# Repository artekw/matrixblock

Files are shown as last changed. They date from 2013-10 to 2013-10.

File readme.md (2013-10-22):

# matrixblock

The goal of this project is create a cape for BeagleBone Black to drive a [Sure Electronic 32x16 LED Display](http://www.sureelectronics.net/goods.php?id=1095).

## Hardware Connection

matrix connection to beaglebone

Power circuit from matrix connector, not BeagleBone! Use power adapter 5V/2A.

## Compile the code

TODO

Examples:

    $ cd examples
    $ make
    $ ./test

Clock:

    $ make
    $ ./clock

### TODO

- python bindings or TCP deamon

### DONE

- print static text
- scroll text
- set brightness (in range 0-16)
- schematics and PCB design of cape
- DT code and EEEPROM firmware
- add RTC clock

### Source

Based on source code from https://github.com/dcuartielles/HT1632c

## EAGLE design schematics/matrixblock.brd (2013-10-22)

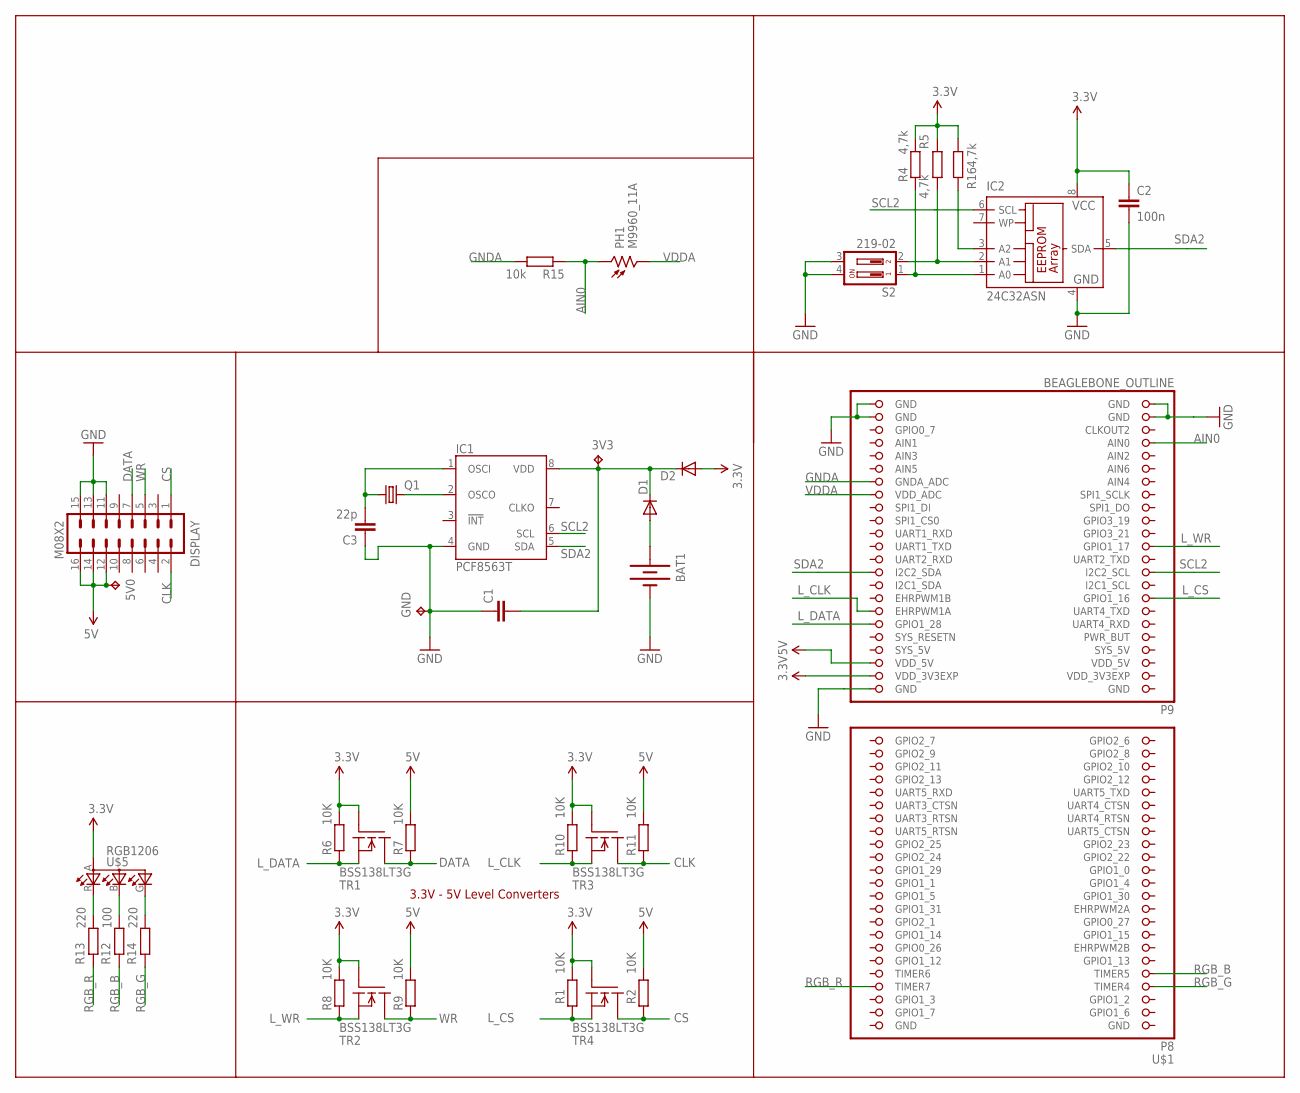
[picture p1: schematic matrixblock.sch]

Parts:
3V3, 5V0: TPTP20R; TP20R
BAT1: BATTERY20PTH; BATTCOM_20MM_PTH
C1: C-EUC0805; C0805
C2: 100n; C0805
C3: 22p; C0805
D1, D2: DIODEHV; DIODE-HV
DISPLAY: M08X2; 2X8
GND: TPTP20R; TP20R
IC1: PCF8563T; SO8
IC2: 24C32ASN; SO-08
PH1: M9960_11A; M9960
Q1: CRYSTALTC26H; TC26H
R1, R2, R6, R7, R8, R9, R10, R11: 10K; R0805
R4, R5, R16: 4,7k; R0805
R12: 100; R0805
R13, R14: 220; R0805
R15: 10k; R0805
S2: 219-02; CTS-219-02
TR1, TR2, TR3, TR4: BSS138LT3G; SOT23
U$1: BEAGLEBONE_OUTLINE; BEAGLEBONE_SHIELD
U$5: RGB1206

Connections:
3.3V: D2.A, R1.1, R6.1, R8.1, R10.1, TR1.1 (G), TR2.1 (G), TR3.1 (G), TR4.1 (G), U$1.50 (VDD_3V3EXP), U$5.A
5V: 5V0.TP, DISPLAY.12, DISPLAY.14, DISPLAY.16, R2.1, R7.1, R9.1, R11.1, U$1.52 (VDD_5V)
AIN0: PH1.1, R15.2, U$1.85 (AIN0)
CLK: DISPLAY.2, R11.2, TR3.3 (D)
CS: DISPLAY.1, R2.2, TR4.3 (D)
DATA: DISPLAY.7, R7.2, TR1.3 (D)
GND: BAT1.2 (-), C1.1, C2.2, C3.1, DISPLAY.11, DISPLAY.13, DISPLAY.15, GND.TP, IC1.4 (GND), IC2.4 (GND), S2.3, S2.4, U$1.1 (GND), U$1.2 (GND), U$1.47 (GND), U$1.48 (GND), U$1.89 (GND), U$1.90 (GND), U$1.91 (GND), U$1.92 (GND)
GNDA: R15.1, U$1.80 (GNDA_ADC)
L_CLK: R10.2, TR3.2 (S), U$1.60 (EHRPWM1A)
L_CS: R1.2, TR4.2 (S), U$1.61 (GPIO1_16)
L_DATA: R6.2, TR1.2 (S), U$1.58 (GPIO1_28)
L_WR: R8.2, TR2.2 (S), U$1.69 (GPIO1_17)
unnamed: BAT1.1 (+), D1.A
unnamed: R12.1, U$5.B (CBLUE)
unnamed: IC1.2 (OSCO), Q1.2
unnamed: C3.2, IC1.1 (OSCI), Q1.1
unnamed: R13.1, U$5.R (CRED)
unnamed: 3V3.TP, C1.2, D1.C, D2.C, IC1.8 (VDD)
unnamed: R14.1, U$5.G (CGREEN)
unnamed: IC2.3 (A2), R16.2
unnamed: IC2.2 (A1), R5.1, S2.2
unnamed: IC2.1 (A0), R4.2, S2.1
RGB_B: R12.2, U$1.9 (TIMER5)
RGB_G: R14.2, U$1.7 (TIMER4)
RGB_R: R13.2, U$1.8 (TIMER7)
SCL2: IC1.6 (SCL), IC2.6 (SCL), U$1.65 (I2C2_SCL)
SDA2: IC1.5 (SDA), IC2.5 (SDA), U$1.66 (I2C2_SDA)
SYS_5V: U$1.53 (SYS_5V)
VCC: C2.1, IC2.8 (VCC), R4.1, R5.2, R16.1
VDDA: PH1.2, U$1.78 (VDD_ADC)
VDD_3V3EXP: U$1.49 (VDD_3V3EXP)
VDD_5V: U$1.51 (VDD_5V)
WR: DISPLAY.5, R9.2, TR2.3 (D)

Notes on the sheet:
3.3V - 5V Level Converters

Board: 2 copper layers, 36 parts (1 on the bottom side), 30 nets, no tracks yet.

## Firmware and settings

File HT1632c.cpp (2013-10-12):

#include "HT1632c.h"
#include "fonts.c"
#include <stdlib.h>
#include <stdio.h>
#include <time.h>
#include "BoneHeader/BoneHeader.h"

// our own copy of the "video" memory; 64 bytes for each of the 4 screen quarters;
// each 64-element array maps 2 planes:
// indexes from 0 to 31 are allocated for green plane;
// indexes from 32 to 63 are allocated for red plane;
// when a bit is 1 in both planes, it is displayed as orange (green + red);
unsigned char ht1632_shadowram[64][4*2] = {0};

// constructor:
// assign pins, one single screen
HT1632c::HT1632c(char bank, char da, char wr, char cs, char cl)
{
      ht1632_data = da;  // Data pin (pin 7 of display connector)
      ht1632_wrclk = wr; // Write clock pin (pin 5 of display connector)
      ht1632_cs = cs;    // Chip Select (pin 1 of display connnector)
      ht1632_clk = cl;   // clock pin (pin 2 of display connector)
      Number_of_Displays = 1;
      CHIP_MAX =  4*Number_of_Displays; // Four HT1632Cs on one board
      X_MAX = 32*Number_of_Displays;
      Y_MAX = 16;

      if (is_exported_gpio(bank * 32 + ht1632_data) == false) {
        export_gpio(bank * 32 + ht1632_data);
        set_gpio_direction(bank * 32 + ht1632_data, "out");
      }
      if (is_exported_gpio(bank * 32 + ht1632_wrclk) == false) {
        export_gpio(bank * 32 + ht1632_wrclk);
        set_gpio_direction(bank * 32 + ht1632_wrclk, "out");
      }
      if (is_exported_gpio(bank * 32 + ht1632_cs) == false) {
        export_gpio(bank * 32 + ht1632_cs);
        set_gpio_direction(bank * 32 + ht1632_cs, "out");
      }
      if (is_exported_gpio(bank * 32 + ht1632_clk) == false) {
        export_gpio(bank * 32 + ht1632_clk);
        set_gpio_direction(bank * 32 + ht1632_clk, "out");
      }

      gpiobank = new GPIO_MMAP(bank);

      if (ht1632_cs > 0) {
        gpiobank->write(ht1632_cs, 1);
      }
      if (ht1632_wrclk > 0) {
        gpiobank->write(ht1632_wrclk, 1);
      }
      if (ht1632_data > 0) {
        gpiobank->write(ht1632_data, 1);
      }
      if (ht1632_clk > 0) {
        gpiobank->write(ht1632_clk, 1);
      }

      ts.tv_sec = 0;
      ts.tv_nsec = DELAY;
}

// constructor:
// assign pins, multiple single screen
HT1632c::HT1632c(char bank, char a, char da, char wr, char cs, char cl)
{
      ht1632_data = da;  // Data pin (pin 7 of display connector)
      ht1632_wrclk = wr; // Write clock pin (pin 5 of display connector)
      ht1632_cs = cs;    // Chip Select (pin 1 of display connnector)
      ht1632_clk = cl;   // clock pin (pin 2 of display connector)
      Number_of_Displays = a;
      CHIP_MAX =  4*Number_of_Displays; // Four HT1632Cs on one board
      X_MAX = 32*Number_of_Displays;
      Y_MAX = 16;

      if (is_exported_gpio(bank * 32 + ht1632_data) == false) {
        export_gpio(bank * 32 + ht1632_data);
        set_gpio_direction(bank * 32 + ht1632_data, "out");
      }
      if (is_exported_gpio(bank * 32 + ht1632_wrclk) == false) {
        export_gpio(bank * 32 + ht1632_wrclk);
        set_gpio_direction(bank * 32 + ht1632_wrclk, "out");
      }
      if (is_exported_gpio(bank * 32 + ht1632_cs) == false) {
        export_gpio(bank * 32 + ht1632_cs);
        set_gpio_direction(bank * 32 + ht1632_cs, "out");
      }
      if (is_exported_gpio(bank * 32 + ht1632_clk) == false) {
        export_gpio(bank * 32 + ht1632_clk);
        set_gpio_direction(bank * 32 + ht1632_clk, "out");
      }

      gpiobank = new GPIO_MMAP(bank);

      if (ht1632_cs > 0) {
        gpiobank->write(ht1632_cs, 1);
      }
      if (ht1632_wrclk > 0) {
        gpiobank->write(ht1632_wrclk, 1);
      }
      if (ht1632_data > 0) {
        gpiobank->write(ht1632_data, 1);
      }
      if (ht1632_clk > 0) {
        gpiobank->write(ht1632_clk, 1);
      }

      //ts.tv_sec = 0;
      //ts.tv_nsec = DELAY;
}

//**************************************************************************************************
//Function Name: OutputCLK_Pulse
//Function Feature: enable CLK_74164 pin to output a clock pulse
//Input Argument: void
//Output Argument: void
//**************************************************************************************************
void HT1632c::OutputCLK_Pulse(void) //Output a clock pulse
{
  gpiobank->write(ht1632_clk, 1);
  gpiobank->write(ht1632_clk, 0);
}


//**************************************************************************************************
//Function Name: OutputA_74164
//Function Feature: enable pin A of 74164 to output 0 or 1
//Input Argument: x: if x=1, 74164 outputs 1. If x?1, 74164 outputs 0.
//Output Argument: void
//**************************************************************************************************
void HT1632c::OutputA_74164(char x) //Input a digital level to 74164
{
  gpiobank->write(ht1632_cs, (x==1 ? 1 : 0));
}


//**************************************************************************************************
//Function Name: ChipSelect
//Function Feature: enable HT1632C
//Input Argument: select: HT1632C to be selected
// If select=0, select none.
// If s<0, select all.
//Output Argument: void
//**************************************************************************************************
void HT1632c::ChipSelect(int select)
{
  unsigned char tmp = 0;
  if(select<0) //Enable all HT1632Cs
  {
    OutputA_74164(0);
    CLK_DELAY;
    for(tmp=0; tmp<CHIP_MAX; tmp++)
    {
      OutputCLK_Pulse();
    }
  }
  else if(select==0) //Disable all HT1632Cs
  {
    OutputA_74164(1);
    CLK_DELAY;
    for(tmp=0; tmp<CHIP_MAX; tmp++)
    {
      OutputCLK_Pulse();
    }
  }
  else
  {
    OutputA_74164(1);
    CLK_DELAY;
    for(tmp=0; tmp<CHIP_MAX; tmp++)
    {
      OutputCLK_Pulse();
    }
    OutputA_74164(0);
    CLK_DELAY;
    OutputCLK_Pulse();
    CLK_DELAY;
    OutputA_74164(1);
    CLK_DELAY;
    tmp = 1;
    for( ; tmp<select; tmp++)
    {
      OutputCLK_Pulse();
    }
  }
}

/*
 * ht1632_writebits
 * Write bits (up to 8) to h1632 on pins ht1632_data, ht1632_wrclk
 * Chip is assumed to already be chip-selected
 * Bits are shifted out from MSB to LSB, with the first bit sent
 * being (bits & firstbit), shifted till firsbit is zero.
 */
void HT1632c::ht1632_writebits (uint8_t bits, uint8_t firstbit)
{
  //printf(" ");
  while (firstbit) {
    //printf((bits&firstbit ? "1" : "0"));
    gpiobank->write(ht1632_wrclk, 0);
    if (bits & firstbit) {
      gpiobank->write(ht1632_data, 1);
    }
    else {
      gpiobank->write(ht1632_data, 0);
    }
    gpiobank->write(ht1632_wrclk, 1);
    firstbit >>= 1;
  }
}

/*
 * ht1632_sendcmd
 * Send a command to the ht1632 chip.
 */
void HT1632c::ht1632_sendcmd (char chipNo, uint8_t command)
{
  ChipSelect(chipNo);
  ht1632_writebits(HT1632_ID_CMD, 1<<2);  // send 3 bits of id: COMMMAND
  ht1632_writebits(command, 1<<7);  // send the actual command
  ht1632_writebits(0, 1);   /* one extra dont-care bit in commands. */
  ChipSelect(0);
}
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

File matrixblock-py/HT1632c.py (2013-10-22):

#!/usr/bin/python2
# -*- coding: utf-8 -*-

import Adafruit_BBIO.GPIO as GPIO   # http://learn.adafruit.com/setting-up-io-python-library-on-beaglebone-black/gpio
import Adafruit_BBIO.ADC as ADC
import numpy as np
from time import sleep

""" Constans """
HT1632_ID_CMD = 4   # ID = 100 - Commands
HT1632_ID_RD = 6   # ID = 110 - Read RAM
HT1632_ID_WR = 5   # ID = 101 - Write RAM
HT1632_ID_BITS = (1<<2)   # IDs are 3 bits

HT1632_CMD_SYSDIS = 0x00  # CMD= 0000-0000-x Turn off oscil
HT1632_CMD_SYSON = 0x01  # CMD= 0000-0001-x Enable system oscil
HT1632_CMD_LEDOFF = 0x02  # CMD= 0000-0010-x LED duty cycle gen off
HT1632_CMD_LEDON = 0x03  # CMD= 0000-0011-x LEDs ON
HT1632_CMD_BLOFF = 0x08  # CMD= 0000-1000-x Blink ON
HT1632_CMD_BLON = 0x09  # CMD= 0000-1001-x Blink Off
HT1632_CMD_SLVMD = 0x10  # CMD= 0001-00xx-x Slave Mode
HT1632_CMD_MSTMD = 0x14  # CMD= 0001-01xx-x Master Mode
HT1632_CMD_RCCLK = 0x18  # CMD= 0001-10xx-x Use on-chip clock
HT1632_CMD_EXTCLK = 0x1C  # CMD= 0001-11xx-x Use external clock
HT1632_CMD_COMS00 = 0x20  # CMD= 0010-ABxx-x commons options
HT1632_CMD_COMS01 = 0x24  # CMD= 0010-ABxx-x commons options
HT1632_CMD_COMS10 = 0x28  # CMD= 0010-ABxx-x commons options
HT1632_CMD_COMS11 = 0x2C  # CMD= 0010-ABxx-x commons options
HT1632_CMD_PWM = 0xA0  # CMD= 101x-PPPP-x PWM duty cycle
HT1632_CMD_BITS = (1<<7)

BLACK = 0
GREEN = 1
RED = 2
ORANGE = 3

FONT = np.array([
  [0x00, 0x00, 0x00, 0x00, 0x00, 0], #   space
  [0x00, 0x00, 0x7d, 0x00, 0x00, 0], # ! Exclaimation Point
  [0x00, 0x70, 0x00, 0x70, 0x00, 0], # " Double Quotes
  [0x14, 0x7f, 0x14, 0x7f, 0x14, 0], # # Pound
  [0x12, 0x2a, 0x7f, 0x2a, 0x24, 0], # $ Dollar Sign
  [0x62, 0x64, 0x08, 0x13, 0x23, 0], # % Percent
  [0x36, 0x49, 0x55, 0x22, 0x05, 0], # & Ampersand
  [0x00, 0x50, 0x60, 0x00, 0x00, 0], # ' Right Single Quote
  [0x00, 0x1c, 0x22, 0x41, 0x00, 0], # ( Left Parenthesis
  [0x00, 0x41, 0x22, 0x1c, 0x00, 0], # ) Right Parenthesis
  [0x08, 0x2a, 0x1c, 0x2a, 0x08, 0], # * Asterisk
  [0x08, 0x08, 0x3e, 0x08, 0x08, 0], # + Plus
  [0x00, 0x05, 0x06, 0x00, 0x00, 0], # , Comma
  [0x08, 0x08, 0x08, 0x08, 0x08, 0], # - Minus
  [0x00, 0x03, 0x03, 0x00, 0x00, 0], # . Period
  [0x02, 0x04, 0x08, 0x10, 0x20, 0], #  Forward Slash

  [0x3e, 0x45, 0x49, 0x51, 0x3e, 0], # 0
  [0x00, 0x21, 0x7f, 0x01, 0x00, 0], # 1
  [0x21, 0x43, 0x45, 0x49, 0x31, 0], # 2
  [0x42, 0x41, 0x51, 0x69, 0x46, 0], # 3
  [0x0c, 0x14, 0x24, 0x7f, 0x04, 0], # 4
  [0x72, 0x51, 0x51, 0x51, 0x4e, 0], # 5
  [0x1e, 0x29, 0x49, 0x49, 0x06, 0], # 6
  [0x40, 0x47, 0x48, 0x50, 0x60, 0], # 7
  [0x36, 0x49, 0x49, 0x49, 0x36, 0], # 8
  [0x30, 0x49, 0x49, 0x4a, 0x3c, 0], # 9

  [0x00, 0x36, 0x36, 0x00, 0x00, 0], # : Colon
  [0x00, 0x35, 0x36, 0x00, 0x00, 0], # ; SemiColon
  [0x00, 0x08, 0x14, 0x22, 0x41, 0], # < Less Than
  [0x14, 0x14, 0x14, 0x14, 0x14, 0], # = Equal
  [0x41, 0x22, 0x14, 0x08, 0x00, 0], # > Greater Than
  [0x20, 0x40, 0x45, 0x48, 0x30, 0], # ? Question Mark
  [0x26, 0x49, 0x4f, 0x41, 0x3e, 0], # @ At

  [0x3f, 0x48, 0x48, 0x48, 0x3f, 0], # A
  [0x7f, 0x49, 0x49, 0x49, 0x36, 0], # B
  [0x3e, 0x41, 0x41, 0x41, 0x22, 0], # C
  [0x7f, 0x41, 0x41, 0x22, 0x1c, 0], # D
  [0x7f, 0x49, 0x49, 0x49, 0x41, 0], # E
  [0x7f, 0x48, 0x48, 0x48, 0x40, 0], # F
  [0x3e, 0x41, 0x41, 0x49, 0x2e, 0], # G
  [0x7f, 0x08, 0x08, 0x08, 0x7f, 0], # H
  [0x00, 0x41, 0x7f, 0x41, 0x00, 0], # I
  [0x02, 0x01, 0x41, 0x7e, 0x40, 0], # J
  [0x7f, 0x08, 0x14, 0x22, 0x41, 0], # K
  [0x7f, 0x01, 0x01, 0x01, 0x01, 0], # L
  [0x7f, 0x20, 0x10, 0x20, 0x7f, 0], # M
  [0x7f, 0x10, 0x08, 0x04, 0x7f, 0], # N
  [0x3e, 0x41, 0x41, 0x41, 0x3e, 0], # O
  [0x7f, 0x48, 0x48, 0x48, 0x30, 0], # P
  [0x3e, 0x41, 0x45, 0x42, 0x3d, 0], # Q
  [0x7f, 0x48, 0x4c, 0x4a, 0x31, 0], # R
  [0x31, 0x49, 0x49, 0x49, 0x46, 0], # S
  [0x40, 0x40, 0x7f, 0x40, 0x40, 0], # T
  [0x7e, 0x01, 0x01, 0x01, 0x7e, 0], # U
  [0x7c, 0x02, 0x01, 0x02, 0x7c, 0], # V
  [0x7f, 0x02, 0x04, 0x02, 0x7f, 0], # W
  [0x63, 0x14, 0x08, 0x14, 0x63, 0], # X
  [0x60, 0x10, 0x0f, 0x10, 0x60, 0], # Y
  [0x43, 0x45, 0x49, 0x51, 0x61, 0], # Z

  [0x00, 0x00, 0x7f, 0x41, 0x41, 0], # [ Left Square Bracket
  [0x20, 0x10, 0x08, 0x04, 0x02, 0], # \ Back Slash
  [0x41, 0x41, 0x7f, 0x00, 0x00, 0], # ] Right Square Bracket
  [0x10, 0x20, 0x40, 0x20, 0x10, 0], # ^ Power
  [0x01, 0x01, 0x01, 0x01, 0x01, 0], # _ Underscore
  [0x00, 0x40, 0x20, 0x10, 0x00, 0], # ` Accent

  [0x02, 0x15, 0x15, 0x15, 0x0f, 0], # a
  [0x7f, 0x05, 0x09, 0x09, 0x06, 0], # b
  [0x0e, 0x11, 0x11, 0x11, 0x02, 0], # c
  [0x06, 0x09, 0x09, 0x05, 0x7f, 0], # d
  [0x0e, 0x15, 0x15, 0x15, 0x0c, 0], # e
  [0x08, 0x3f, 0x48, 0x40, 0x20, 0], # f
  [0x08, 0x14, 0x15, 0x15, 0x1e, 0], # g
  [0x7f, 0x04, 0x08, 0x08, 0x07, 0], # h
  [0x00, 0x01, 0x2f, 0x01, 0x00, 0], # i
  [0x02, 0x01, 0x11, 0x5e, 0x00, 0], # j
  [0x7f, 0x04, 0x0a, 0x11, 0x00, 0], # k
  [0x00, 0x41, 0x7f, 0x01, 0x00, 0], # l
  [0x1f, 0x10, 0x0c, 0x10, 0x0f, 0], # m
  [0x1f, 0x08, 0x10, 0x10, 0x0f, 0], # n
  [0x0e, 0x11, 0x11, 0x11, 0x0e, 0], # o
  [0x1f, 0x14, 0x14, 0x14, 0x08, 0], # p
  [0x08, 0x14, 0x14, 0x0c, 0x1f, 0], # q
  [0x1f, 0x08, 0x10, 0x10, 0x08, 0], # r
  [0x09, 0x15, 0x15, 0x15, 0x02, 0], # s
  [0x10, 0x7e, 0x11, 0x01, 0x02, 0], # t
  [0x1e, 0x01, 0x01, 0x02, 0x1f, 0], # u
  [0x1c, 0x02, 0x01, 0x02, 0x1c, 0], # v
  [0x1e, 0x01, 0x02, 0x01, 0x1e, 0], # w
  [0x11, 0x0a, 0x04, 0x0a, 0x11, 0], # x
  [0x18, 0x05, 0x05, 0x05, 0x1e, 0], # y
  [0x11, 0x13, 0x15, 0x19, 0x11, 0], # z

  [0x00, 0x08, 0x36, 0x41, 0x00, 0], # [ Left Braces
  [0x00, 0x00, 0x7f, 0x00, 0x00, 0], # | Pipe
  [0x00, 0x41, 0x36, 0x08, 0x00, 0]])
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

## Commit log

2013-10-06 Preliminary implementation HT1632c driver in Python
2013-10-06 Import of modified files originally from http://pignology.net/ Changes are:
    * Enabled UART 2,3,5
    * Added pin mux configuration for the aformentioned UARTS
    and disabled heatbeat at usr0 LED(by me)
2013-10-06 add led systemd service

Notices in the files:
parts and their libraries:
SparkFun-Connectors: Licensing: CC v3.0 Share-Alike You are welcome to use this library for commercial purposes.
